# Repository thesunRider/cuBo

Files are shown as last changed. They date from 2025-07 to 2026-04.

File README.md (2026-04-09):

# cuBo
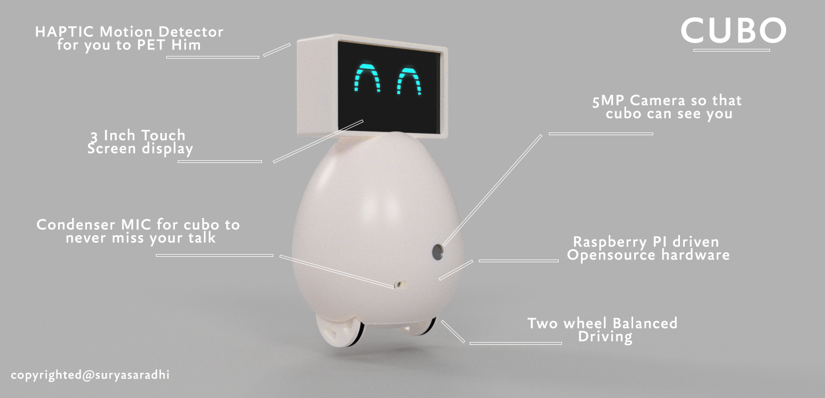
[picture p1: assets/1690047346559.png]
Description

### Autonomous Companion Robot for Modern Homes

**cuBo** is an open-source, interactive, autonomous companion robot designed for modern homes, running on a Raspberry Pi Zero 2 W with Raspberry Pi OS Bullseye Lite. Developed by **Leena Kashyap**,**Suryasaradhi Balarkan** and **Haris Mujeeb**.cuBo blends affordable hardware with AI-based software to deliver:

* Video streaming
* Expressive robotic eye animations
* Voice interaction
* Sensor-based gesture control
* Mobility

cuBo functions as a home automation hub, elderly care companion, educational assistant, and mobile surveillance system, requiring minimal user management. It reacts to touch and voice with emotional expressions, making it an engaging and relatable companion.

For setting up cubo : read implementations.md
---

## 🎯 Purpose

cuBo addresses key challenges in smart home robotics:

* **Emotional Interaction**: Unlike static assistants (e.g., Alexa, Google Home), cuBo offers physical movement and expressive animations.
* **Elderly Care**: Provides companionship, reminders, and emergency alerts for seniors.
* **Affordability**: Uses low-cost components to make personal robotics accessible.
* **Unified Automation**: Acts as a central hub for smart devices, schedules, and communication.

---

## 🚀 Features

* **Video Streaming:** 1080p30 video over UDP with `libcamera-vid` + `ffmpeg` for face/object tracking.
* **Display:** Robotic “RoboEyes” animations on a 3.5” SPI LCD (`/dev/fb0` framebuffer).
* **Audio:** Speech recognition (VOSK/Whisper) and audio playback via I2S.
* **Mobility:** 28BYJ-48 stepper motors for movement (head/wheel), controlled via Arduino Micro.
* **Sensors:** Compass (QMC5883P), TOF sensor (VL53L3CX), touch sensors for gesture input.
* **Automation:** Flask server for smart device control, scheduling, and remote access.

---

## Demo Video 
The below is Unfinished first cuBo prototype

https://github.com/user-attachments/assets/90a2a3a3-cf43-4fe5-9dd7-d7a50253ca3a

## 🧰 Hardware Components

| Component | Function |
| --- | --- |
| Raspberry Pi Zero 2 W | Main processor (AI, video, audio, control) |
| Arduino Micro | Motor and sensor control |
| OV5640 Camera | Video streaming & object detection |
| INMP411 Microphone | Voice input |
| 3.5" SPI LCD | Display animations/UI |
| MAX98357A Speaker | Audio output |
| Touch Sensor | Gesture/touch detection |
| 28BYJ-48 Stepper Motors | Movement (head/wheels) |
| ULN2003 Driver Board | Stepper motor driver |
| VL53L3CX TOF Sensor | Distance measurement (obstacle detection)  |
| QMC5883P Compass | Orientation detection |
| 3.7V Li-ion Battery | Power source |
| TP4056 Module | Battery charging & protection |
| 5V Boost Converter | 5V regulated power |
| Flask Server (via WiFi) | Remote control and streaming backend |

---

## 💾 Software Stack

### Raspberry Pi

* **OS:** Raspberry Pi OS Bullseye Lite
* **Languages:** Python, C++
* **Frameworks:**

  * ROS (sensor & navigation control)
  * Flask (web interface & automation)
  * ORB-SLAM (planned for future navigation)
* **AI:**

  * VOSK/Whisper for speech recognition
  * Ollama (planned for advanced AI chat)
* **Libraries:** `numpy`, `pyserial`, `picamera`, `libcamera-apps`, `ffmpeg`, `U8glib`, `PIGPIO`
* **Networking:** WiFi (video streaming, remote server)

### Arduino

* **Libraries:** `TinyStepper_28BYJ_48`, `ezButton`, `Wire`
* **Functions:** Motor & sensor control, UART bridge for Pi communication

### Design Tools

* **Fusion 360:** CAD modeling
* **KiCad:** PCB design
* **Flutter:** Mobile App (optional)

---

## ⚙️ Setup Instructions

### 1. Raspberry Pi Configuration

* Install Raspberry Pi OS Bullseye Lite
* Network Setup:

  ```bash
  nmap -p 22 --open -sV <subnet>.0/24  # Scan
  ping <ip>                            # Test
  ```
* Enable mDNS:

  ```bash
  sudo apt update
  sudo apt install avahi-daemon
  sudo systemctl enable avahi-daemon
  sudo systemctl start avahi-daemon
  sudo raspi-config  # Set hostname
  ping <hostname>.local
  ```

### 2. Camera & Streaming

* Enable camera (`raspi-config` + `/boot/config.txt`)
* Install tools:

  ```bash
  sudo apt install ffmpeg libcamera-apps tio
  ```
* Stream Video:

  ```bash
  libcamera-vid -t 0 -g 10 --bitrate 4500000 --inline --width 1920 --height 1080 --framerate 30 --rotation 180 --codec libav --libav-format h264 --av-sync 200000 -n -o udp://<receiver-ip>:1234
  ```
* View Stream:

  ```bash
  ffplay -fflags nobuffer -flags low_delay -framedrop udp://<receiver-ip>:1234
  ```

### 3. Audio Setup

* Enable I2S in `/boot/config.txt`:

  ```bash
  dtparam=i2s=on
  dtoverlay=googlevoicehat-soundcard
  ```
* Test Audio:

  ```bash
  aplay -l
  speaker-test
  arecord -d 5 test.wav
  aplay test.wav
  ```

### 4. Display Setup

* Connect 3.5" SPI LCD (via guide)
* Framebuffer Test:

  ```python
  import numpy as np
  fb = np.memmap('/dev/fb0', dtype='uint8', mode='w+', shape=(1024, 1280, 4))
  fb[:] = [255, 0, 0, 255]  # Blue screen
  ```

### 5. Sensor & Motor Control

* Upload Arduino code for stepper motors, buttons, compass, UART.
* Serial communication via `/dev/ttyS0` or `/dev/ttyUSB0`.
* Command Format:

  * `sm` (motor control), `swa` (button input), `cmps` (compass data).

### 6. RoboEyes Animation

* Expressive eye animations at 7 FPS:

  ```python
  robo = RoboEyes(lcd, 480, 320, frame_rate=7, on_show=robo_show)
  robo.set_auto_blinker(True, 4, 2)
  robo.set_idle_mode(True, 5, 2)
  robo.mood = DEFAULT
  robo.curious = True
  ```

---

## 🛠️ Implementation

* **Design:** Modeled in Fusion 360 with multiple design iterations.
* **Hardware:** Integrated stepper motors, sensors, audio, display.
* **Software:**

  * Python: AI, video, audio, LCD, server
  * Arduino: Motor & sensor control
  * Flask: Web interface & remote control
* **Testing:** Verified video streaming, sensor inputs, and animations.

---

## 🏠 Use Cases

* **Home Automation:** Control smart devices and routines.
* **Elderly Care:** Provide companionship, reminders, and emergency alerts.
* **Education:** Engage children with learning tools.
* **Surveillance:** Mobile camera for security monitoring.
* **Ambient:** Display info, play music, and show notifications.

---

## 🔮 Future Plans

* Integrate ORB-SLAM for autonomous navigation.
* Develop IoT backend for device integrations.
* Enhance AI with Whisper or ChatGPT.
* Integrate popular apps (Skype, WhatsApp).
* Connect to Google IoT for alarms and calendars.
* Add native language speech support.
* Design compact PCB for space optimization.
* Upgrade mechanical design with faster motors.
* Improve gesture recognition accuracy.

## 📄 License

MIT License

---

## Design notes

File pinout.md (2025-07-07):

## Connections

### Arduino
4 - step 1
5 - step 1
6 - step 1
7 - step 1

8 - step 2
9 - step 2
10 - step 2
11 - step 2

2 - sda
3 - scl

->  Connected: TMF8801, QMC5883L , ULNBYJ-248 ,  Touch sensors 

### Rpi Zero

bcm21 - din
bcm20 - dout
bcm19 - lrclk
bcm18 - bclk
bcm4 - Arduino Reset
bcm14 - Uart RX
bcm15 - Uart TX

bcm17 - TP_IRQ
bcm24 - LCD_RS	
bcm10 - LCD_SI / TP_SI	
bcm9 - TP_SO	
bcm25 - RST	
bcm11 - LCD_SCK / TP_SCK	
bcm8 - LCD_CS	
bcm7 - TP_CS	

-> Connected: INMP441, MAX98357A , OV5640 , Display

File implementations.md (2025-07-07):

## Pi Zero 2 W Setup
Pi Zero 2 OS: Bullseye Lite

Scanning for the pi before mDns is enabled can be done using
```bash
ipconfig or ifconfig (Windows or linux)
nmap -p 22 --open -sV subnet.0/24
ping <Scanned ip>
```

1. Setup mDNS on Raspberry pi
On windows you can use: https://support.apple.com/kb/DL999 to install mDNS resolution

```bash
sudo apt update
sudo apt install avahi-daemon
sudo systemctl enable avahi-daemon
sudo systemctl start avahi-daemon
systemctl status avahi-daemon
sudo raspi-config #set Hostname here

ping yourhostname.local #should work now
```

2. Setting up Camera and Streaming
1. Enable camera autodetect in boot config
2. Enable Camera in raspi-config
3. Install tools
```bash
sudo apt install ffmpeg -y
sudo apt install libcamera-apps
sudo apt-get install tio
```

4. Stream accessed using ffmplay commandon network using:
```bash
libcamera-vid -t 0 -g 10 --bitrate 4500000 --inline --width 1920 --height 1080 --framerate 30 --rotation 180 --codec libav --libav-format h264  --av-sync 200000 -n -o  udp://(recievingcomputersip):1234
ffplay -fflags nobuffer -flags low_delay -framedrop udp://(recievingcomputersip):1234
```
5. For autostart follow: https://medium.com/@celecavac/building-your-own-wifi-camera-with-raspberry-pi-zero-w-6d59b494e0c9

3. Setting Up MIC and Speaker Simultaneously

PI Zero has only one I2S peripheral, we are sharing the right channel for ASpeaker output and the left channel for audio in, for this we are using the `dtoverlay=rpigooglevoicehat-ssoundcard`
Enable overlays;
```bash
#This is /boot/config.txt
dtparam=i2s=on
dtoverlay=googlevoicehat-soundcard
```

##  USeful tools

Tools used in setting up pi zero 2 w streaming section
```bash
1. aplay -l
2. speaker-test
3. arecord -l
4. arecord -d 5 test.wav
5. aplay test.wav
6. v4l2-ctl --list-devices #list cameras
7. libcamera-hello
8. arecord --dump-hw-params -D hw:<card_id>,<device_id>
9. ls -l /dev/serial*
10. ls -l /dev/
11. fbset -fb /dev/fb0 
12. tvservice -d edid # Retrieve EDID settings from monitor and write into a file called "edid"
13. edidparser edid # Parse the file we just created to see what the attached monitor is capable of
```

4. Setup Display
Check display Connections
Follow: https://techeonics.com/setting-up-lcd-display-with-raspberry-pi/

No need for any window manager, we can directly write to the fb as follows
```python
import numpy as np

# Map the screen as Numpy array
# N.B. Numpy stores in format HEIGHT then WIDTH, not WIDTH then HEIGHT!
# c is the number of channels, 4 because BGRA
h, w, c = 1024, 1280, 4
fb = np.memmap('/dev/fb0', dtype='uint8',mode='w+', shape=(h,w,c)) 

# Fill entire screen with blue - takes 29 ms on Raspi 4
fb[:] = [255,0,0,255]

# Fill top half with red - takes 15 ms on Raspi 4
fb[:h//2] = [0,0,255,255]

# Fill bottom right quarter with green - takes 7 ms on Raspi 4
fb[h//2:, w//2:] = [0,255,0,255] 
```

Rewriting robot eyes to fit framebuffer

Need to implement swipe gestures and distance detection in sensor

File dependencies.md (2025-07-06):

Arduino dependencies:
	TinyStepper_28BYJ_48.h

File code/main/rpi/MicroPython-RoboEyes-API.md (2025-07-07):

# Introduction

This document describe the __RoboEyes__ and __Sequences__ classes.

# RoboEyes class

The RoboEyes is the main class used to control the properties and animation of the Eyes.

Note that `self`  is part of the Python class definition.

## \_\_init\_\_() method

Class constructor.

```
def __init__(self, fb, width, height, frame_rate=20, on_show=None, bgcolor=BGCOLOR, fgcolor=FGCOLOR ):
```

* __fb__ : FrameBuffer into which the RoboEyes will be drawed the Eyes.
* __width__ : Width of the FrameBuffer in Pixels
* __height__ : Height of the FrameBuffer in Pixels
* __frame_rate__ : Max frame rate to refresh the screen. Higher is the autorized rate, and smoother the animation will be.
* __on_show__ : callback event executed by RoboEyes when framebuffer data should be sent to the display.
* __bgcolor__ : color used for the background. This value is sent immediately to the FrameBuffer drawing routines.
* __fgcolor__ : color used for the foreground drawing.

Minimal setup example:

``` python 
from machine import I2C, Pin
from roboeyes import *
import ssd1306
import time

i2c = I2C( 1, sda=Pin.board.GP6, scl=Pin.board.GP7 )
lcd = ssd1306.SSD1306_I2C( 128, 64, i2c, addr=0x3d )

# RoboEyes callback event
def robo_show( roboeyes ):
	global lcd
	lcd.show()

robo = RoboEyes( lcd, 128, 64, frame_rate=100, on_show = robo_show )

while True:
	robo.update() 
```

## update() method

The `update` method is responsible for drawing each iteration of RoboEyes animation. The call to `update` only perform drawing at the proper timing to respect the desired frame_rate. The `update` method is also responsible to trigger the `on_show` event.

When called to early the method will simply return execution to the callee. 

The `update` method is also responsible to schedule the steps of a started sequence (see later in this document)

Do not hesitate to call `update` as often as possible. 

## set_auto_blinker() method

Set automated eye blinking with minimal blink interval and blink interval variation range.

Note that set_auto_blinker() must be disabled when using the `close()` and `open()` methods.

``` python
def set_auto_blinker( self, active, interval=None, variation=None):
```

* __active__ : use the constant ON and OFF. When activating, the `interval` (default 1) and `variation` (default 4) should ne set.
* __interval__ : minimum interval between 2 consecutive blink (in seconds).
* __variation__ : maximum random time to add to `interval` for the next blink (in seconds).

Example: 

``` python 
robo.set_auto_blinker( ON, 3, 2)
```

## set_idle_mode() method

Set automated eye repositioning with minimal time interval and time interval variation range.

``` python
def set_idle_mode( self, active, interval=None, variation=None)
```

* __active__ : use the constant ON and OFF. When activating, the `interval` (default 1) and `variation` (default 4) should ne set.
* __interval__ : minimum interval between 2 consecutive repositionning (in seconds).
* __variation__ : maximum random time to add to `interval` for the next repositionning (in seconds).

Example: 

``` python 
robo.set_idle_mode( ON, 2, 2)
```
## EYE GEOMETRY

### eyes_width() method

Set the width of each eyes.  Default value is 45 pixels.

```
def eyes_width( self, leftEye, rightEye)
```

Here an example of distinct eye width and eye height.

Distinct height & width for each eye

### eyes_height() method

Set the height of each eye. The default value is 45 pixels.

```
def eyes_height( self, leftEye, rightEye )
```

### eyes_radius() method

Define the radius to apply on corners of each eye. The default value is 8 pixels.

Using a 0 pixel radius will show __SQUARE eye__. Having `Height = Width` and `radius = Height / 2` will show a __ROUND eye__.

```
def eyes_radius( self, leftEye, rightEye)
```

Here an example of disctinct radius value.

Distinct radius for each eye

### eyes_spacing() method

Set the space between the both eyes. The default value is 10 pixels.

Space can be lower and negative, giving a very special look to your eyes.

```
def eyes_spacing( self, space )
```

Example:

``` Python
from machine import I2C, Pin
from roboeyes import *
import ssd1306
import time

# Raspberry-Pi Pico - I2C(1)
i2c = I2C( 1, sda=Pin.board.GP6, scl=Pin.board.GP7 )
# Adafruit 938 : Monochrome 1.3" 128x64 OLED graphic display - SSD1306
# SSD1306_I2C is a descendant of FrameBuf 
lcd = ssd1306.SSD1306_I2C( 128, 64, i2c, addr=0x3d )

# RoboEyes callback event
def robo_show( roboeyes ):
	global lcd
	lcd.show()

robo = RoboEyes( lcd, 128, 64, frame_rate=100, on_show = robo_show )
# Define some automated eyes behaviour
robo.set_auto_blinker( ON, 3, 2) 
robo.set_idle_mode( ON, 2, 2) 
# Round Eye definition
robo.eyes_width(45, 45) 
robo.eyes_height(45, 45)
robo.eyes_radius(8, 8)
robo.eyes_radius(22, 22)
robo.eyes_spacing(-7)

while True:
	robo.update()  
```

Which produce the following eyes.

Round Eyes with negative spacing

### Sequences property

Give access to various sequence. See the definition of the `Sequences` class.

### cyclops property

Setting the `cyclops` boolean property will activate the Cyclop mode (show only one eyes).

```
@cyclops.setter
def cyclops( self, enabled ):
```

Notice: the `def set_cyclops( self, value )` can be used for creating lambda expression.

``` python
from machine import I2C, Pin
from roboeyes import *
import ssd1306
import time

# Raspberry-Pi Pico - I2C(1)
i2c = I2C( 1, sda=Pin.board.GP6, scl=Pin.board.GP7 )
# Adafruit 938 : Monochrome 1.3" 128x64 OLED graphic display - SSD1306
# SSD1306_I2C is a descendant of FrameBuf 
lcd = ssd1306.SSD1306_I2C( 128, 64, i2c, addr=0x3d )

# RoboEyes callback event
def robo_show( roboeyes ):
	global lcd
	lcd.show()

robo = RoboEyes( lcd, 128, 64, frame_rate=100, on_show = robo_show )
# Define some automated eyes behaviour
robo.set_auto_blinker( ON, 3, 2) 
robo.set_idle_mode( ON, 2, 2) 
# Cyclop Eye definition
robo.eyes_width(20, 20) 
robo.eyes_height(45, 45)
robo.eyes_radius(0, 0)
robo.cyclops = True

while True:
	robo.update()  
```

Which produce the following eye.

Cyclops Eye

## mood property

Setting the `mood` property will update the dynamic eyes behaviour.

The possible values are the following constants: __DEFAULT, TIRED, ANGRY, HAPPY, FROZEN, SCARY, CURIOUS__.

```
@mood.setter
def mood( self, mood )
```

Notice: the `def set_mood( self, mood )` can be used for creating lambda expression.

The __DEFAULT__ value is the default mode where eyes a usually open.

The __TIRED__ will partially close the eyelid on the eyes.

The __ANGRY__ will make the eyebrows pointing back between the eyes.

The __HAPPY__ will curves/bump up the eyes.

The __FROZEN__ will make eyes slightly shaking from left-to-right (like your head would do when you are frozen).

The __SCARY__ will partially close the eyes and made it slightly shaking from top-to-bottom (like your jaw would do if you are afraid).

The __CURIOUS__ will increase the size of the eye near of the left or right border (behind the scene, this activates the `curious` property).

Example:

``` python
robo.mood = HAPPY 
```

## position property

Move the eyes on a given border/corner of the screen accordingly to the value __N, NE, E, SE, S, SW, W, NW__. The value __DEFAULT__ can be used to horizontally and vertically centered the eye.

```
@position.setter
def position( self, direction )
```

Compatible with an active `set_idle_mode()`, eye will start moving again after the eyes had moved in the target position. 

Notice: the `def set_position( self, direction )` can be used for creating lambda expression.

Example:

``` python
robo.position = SW 
```

## curious property

Set curious mode as the `robo.mood=CURIOUS` would do with a True / False parameter.

The respectively outer eye gets larger when looking left or right.

``` python
curious.setter
def curious( self, enable )
```

Notice: the `def set_curious( self, enable )` can be used for creating lambda expression.

## confuse() method

Make the eyes flicker left-and-right in a rather large distance (20 pixels) like shaking the head. 

The animation duration is about 500 ms.

``` python
def confuse( self )
```

## laugh() method 

Make the eyes jumping up and down (like laughing out loud) for 500 ms. This short animation is played once.

Notice that setting the `mood` to __HAPPY__ would gives a great result.

``` python
def laugh( self )
```

## blink() method

Activate eye blink sequence. This call make sense only when autoblinker is disable.

``` python
def blink( self, left=None, right=None )
```

## wink() method
Make either a left, either a right eye wink.

This call __disable the autoblinker and idle mode__.

``` python
def wink( self, left=None, right=None )
```

Example:

``` python
robo.wink( right=True )
```

## open() & close() method

Open or close the eyes. When closed, the eyes are reduced to a single line.

__Idle mode must be disabled__ when using thoses methods. See the [test_anim_sequence.py](examples/test_anim_sequence.py) .

## horiz_flicker() method

horizontal Eyes shaking/flickering. This basic method is used for several effect (eg: FROZEN mood).

``` python
def horiz_flicker( self, enable, amplitude=None )
```
* __enable__ : True/False to activate/deactivate horizontal Eyes flickering.
* __amplitude__ : flickering amplitude in pixels.

## vert_flicker() method

Same as `horiz_flicker()` but for vertical movement.

# Sequences class

The Sequences class is a list containing `Sequence`. Each `Sequence` contains a list of __Step__ (formmally `StepData` class).

The `RoboEyes.sequences` is used to define several `Sequence` (a `Sequence` is like one animation). 

Each `Sequence` can be started at any time by calling its `start()` method. When started, the `sequence` executes its various steps it contains, execution made at the right timing. 

Example:

The following code defines the `Sequence` named "demo" and the various steps it contains.

``` python
robo = RoboEyes( lcd, 128, 64, frame_rate=100, on_show = robo_show )

# RoboEyes can store several animation sequences 
#   Lets create the sequence ZERO
seq = robo.sequences.add( "demo" )
seq.step( 2000, lambda robo : robo.open() ) # at 2000 ms from start --> open eyes.
seq.step( 4000, lambda robo : robo.set_mood(HAPPY) ) # Lamba must call function! Cannot assign property! 
seq.step( 4010, lambda robo : robo.laugh() )
seq.step( 6000, lambda robo : robo.set_mood(TIRED) )
seq.step( 8000, lambda robo : robo.set_mood(DEFAULT) )
seq.step( 9000, lambda robo : robo.close() )
seq.step( 10000, lambda robo : print(seq.name,"done !") )  # Also signal the end of sequence at 10 sec
```

## add() method 

This method is called prior to define a new sequence of step (say: to define a new "animation").

Create a `Sequence` object, give it a name and register it into the `Sequences` list. 

The method returns a reference to the created `Sequence` objet. 

``` python 
def add( self, name  )
```

## done property

Check if all defined `Sequence` are done. The property is True when all started `Sequence` are done! (Note: a not started `Sequence` is always done).

``` python
@property
def done( self )
```

## update() method

That method check if any started `Sequence` it contains have a pending __Step__ to execute. If such then the pending __Step__ are executed.

``` python
def update( self )
```

# Sequence class

The `Sequence` class is container of __Step__ s (`StepData`). Each __Step__ defines a task to perform at a given time (after Sequence is started).

## step() method 

This method is used to add the definition of new __Step__ into the sequence.

``` python
def step( self, ms_timing, _lambda )
```
	
* __ms_timing__ : time in milliseconds after the Sequence start. Time when the __Step__ must be executed.
* __\_lambda__ : the function to execute. Must be a function or lambda expression receiving a RoboEyes instance as parameter.

As the \_lambda receives the robo (RoboEyes instance), the step can run action (method call) to change the Eyes behavior, mood, animation, etc.

Due to the limitation of the MicroPython parser, the lambda expression cannot make property assignation. This is the raison why the RoboEyes properties hase their equivalent `set_xxx()` method.

In the following lines:

``` python
seq.step( 6000, lambda robo : robo.set_mood(TIRED) )
seq.step( 8000, lambda robo : robo.set_mood(DEFAULT) )
```

The mood of the RoboEyes will be set to TIRED 6 seconds after the start of the sequence. The mood will be changed again to DEFAULT 8 seconds after the sequence start.

The `Sequence` will be set to "done" immediately after execution of the last __Step__. 

IF the `Sequence` must last longer than last step execution THEN just add a final step with a `print()` statement. That will delay the end of sequence execution until the `print()` is executed.

## start() method

Start the execution of the `Sequence`... meaning the execution of the __Step__ contained into the `Sequence`.

This method also set the _start_ flag and keeps track of the starting time (required to executes the __Step__ at the right time).

## reset() method

Reset the _start_ flag of the sequence as well as the `done` flag of all the __Step__ .

``` python
def reset( self )
```

## done property

Return `True` when all the steps of a started sequence are executed (are `done`).

A not started `Sequence` is always `done`! So the property return False only when one or more steps to be executed.

``` python
@property
def done( self )
```

## Update() method

Check if one of the defined __Step__s have to be executed. If so, it does it by calling the step.update().

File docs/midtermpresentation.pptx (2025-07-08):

## CUBO – Implementation Updates

Ubiquitous Lab Systems – MID TERM PRESENTATION

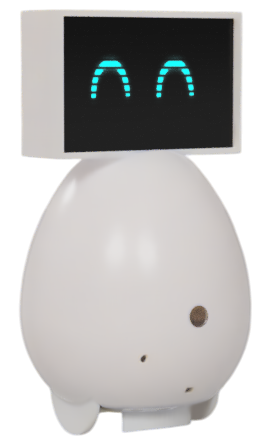
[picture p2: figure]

## Implementation Overview

1. Implemented the CAD model
2. Code testing
3. Connection Modelling
4. Simulation

## Hardware Procurement

Hardware Used:

1. Raspberry Pi Zero W - 1x
2. ULN8BYJ - Stepper motor - 2x
3. 5MP Camera Module for Raspberry Pi Zero
4. TOF Sensor (VL53L0x) - 1x or equivalent
5. 4inch LCD Module with touch screen SPI preferred - 1x
6. Capacitive touch sensor - 2x
7. Electret Mic module - 2x
8. Battery Overvoltage Protector - 1x
9. Battery Charger Module - 1x
10. Stepper Driver for ULN8BYJ - 1x
11. Wireless charging module - 1x
12. GPS module - 1x
13. IMU Module - 1x
14. IR obstacle sensor - 2x

## Implemented Code

Implemented Test code in python for :
1. Stepper movement with encoding
2. Camera realtime streaming
3. LCD Display with robotic eyes
4. Capacitive touch sensor
5. Sound Recording and Streaming
6. Ollama based model for AI end
7. Whisper AI backend for speech recognition

## Setbacks

1. No components available
2. Deadlines shifted
3. Code compilation time > 1 minute

## Expected Outcome

1. AI integrated bot
2. Speech recognition
3. Movement control by AI
4. Basic App Integration

## THANK YOU

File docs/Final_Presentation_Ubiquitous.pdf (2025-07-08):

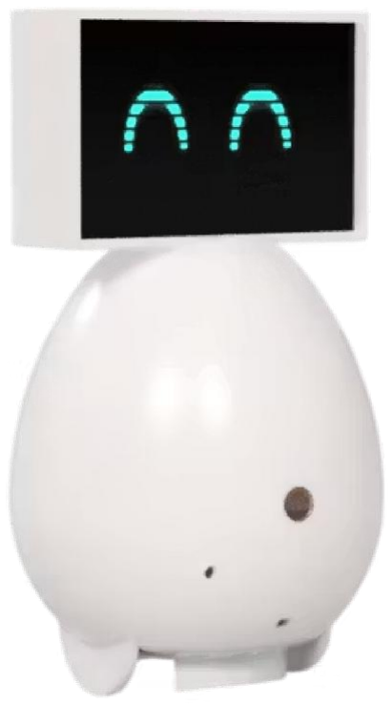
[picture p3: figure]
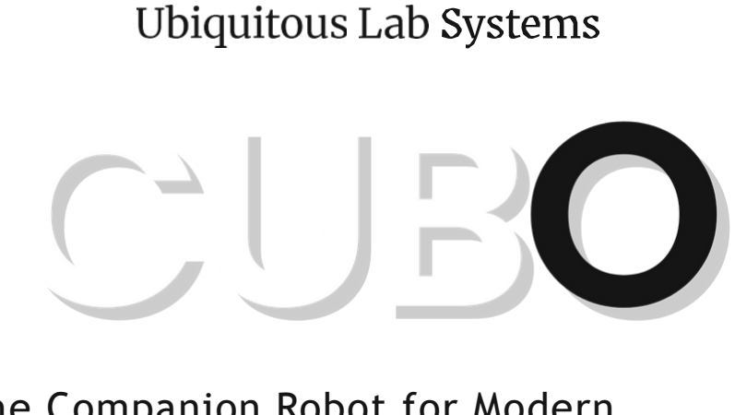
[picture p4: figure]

Team :
Leena Kashyap – 1786572
Suryasaradhi Balarkan - 1840580

The Companion Robot for Modern Homes

# Final Presentation

## The Problem

•

•

•

•

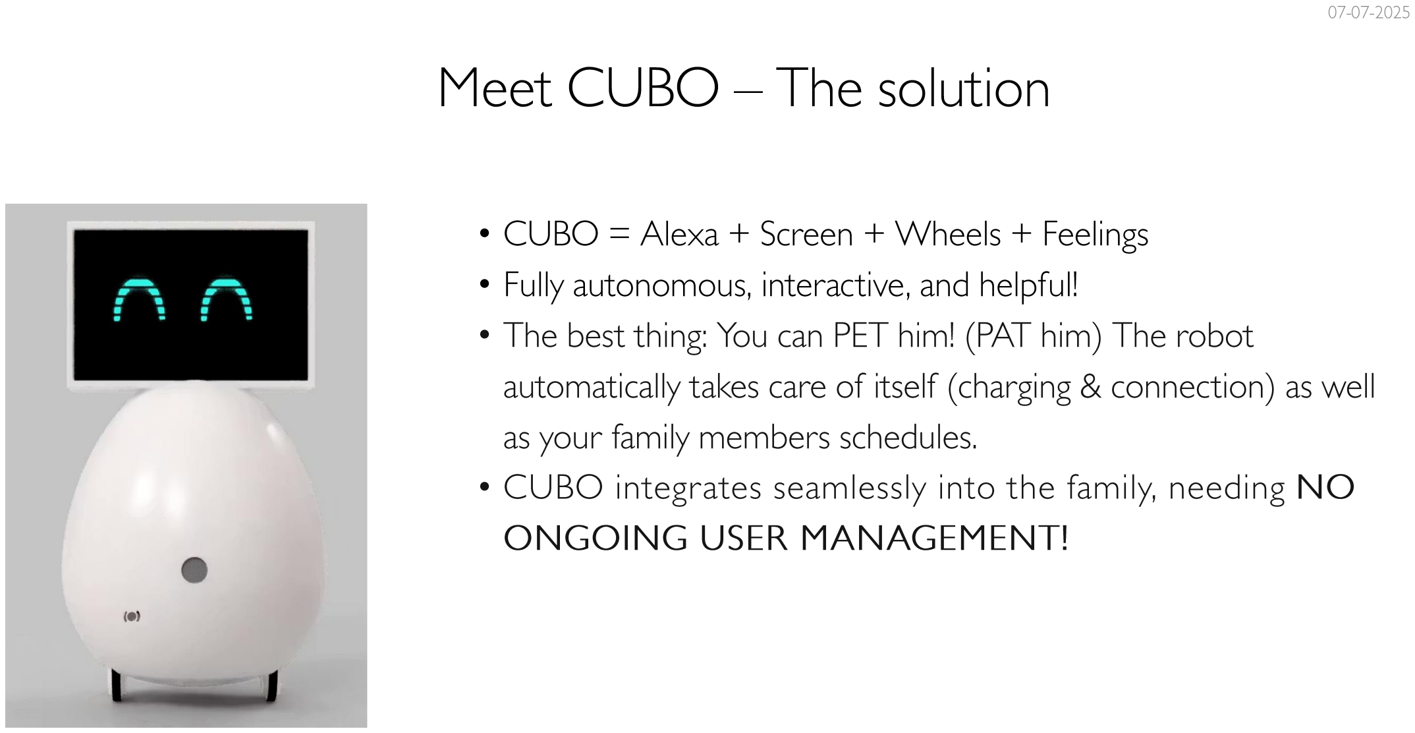
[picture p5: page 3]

••••

••••

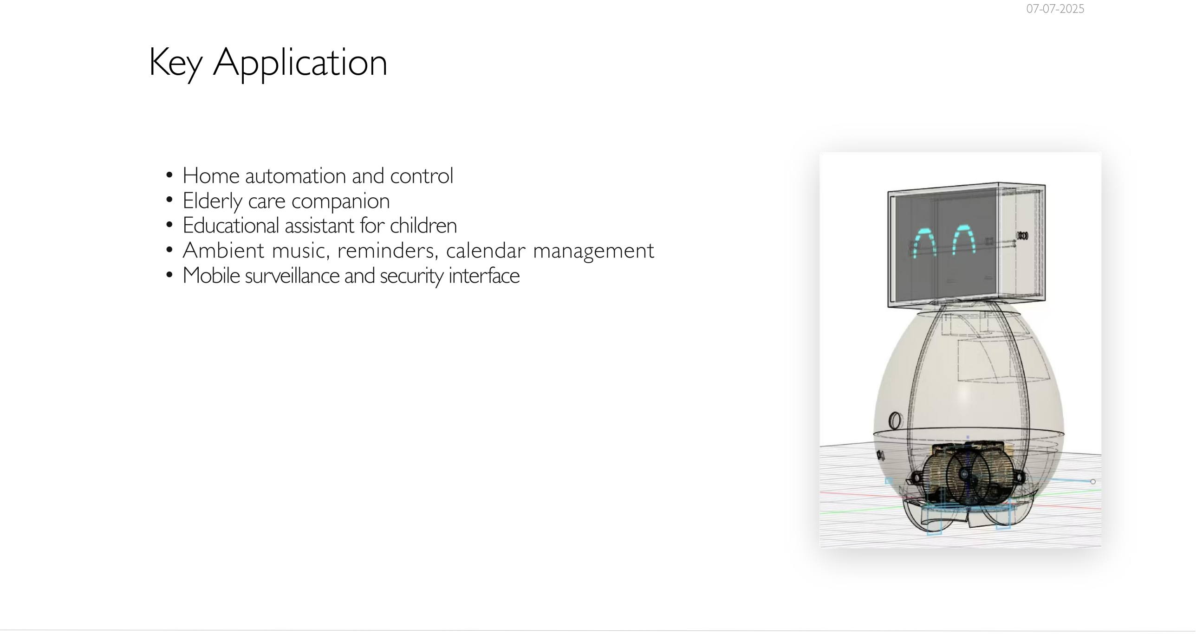
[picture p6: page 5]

•••••

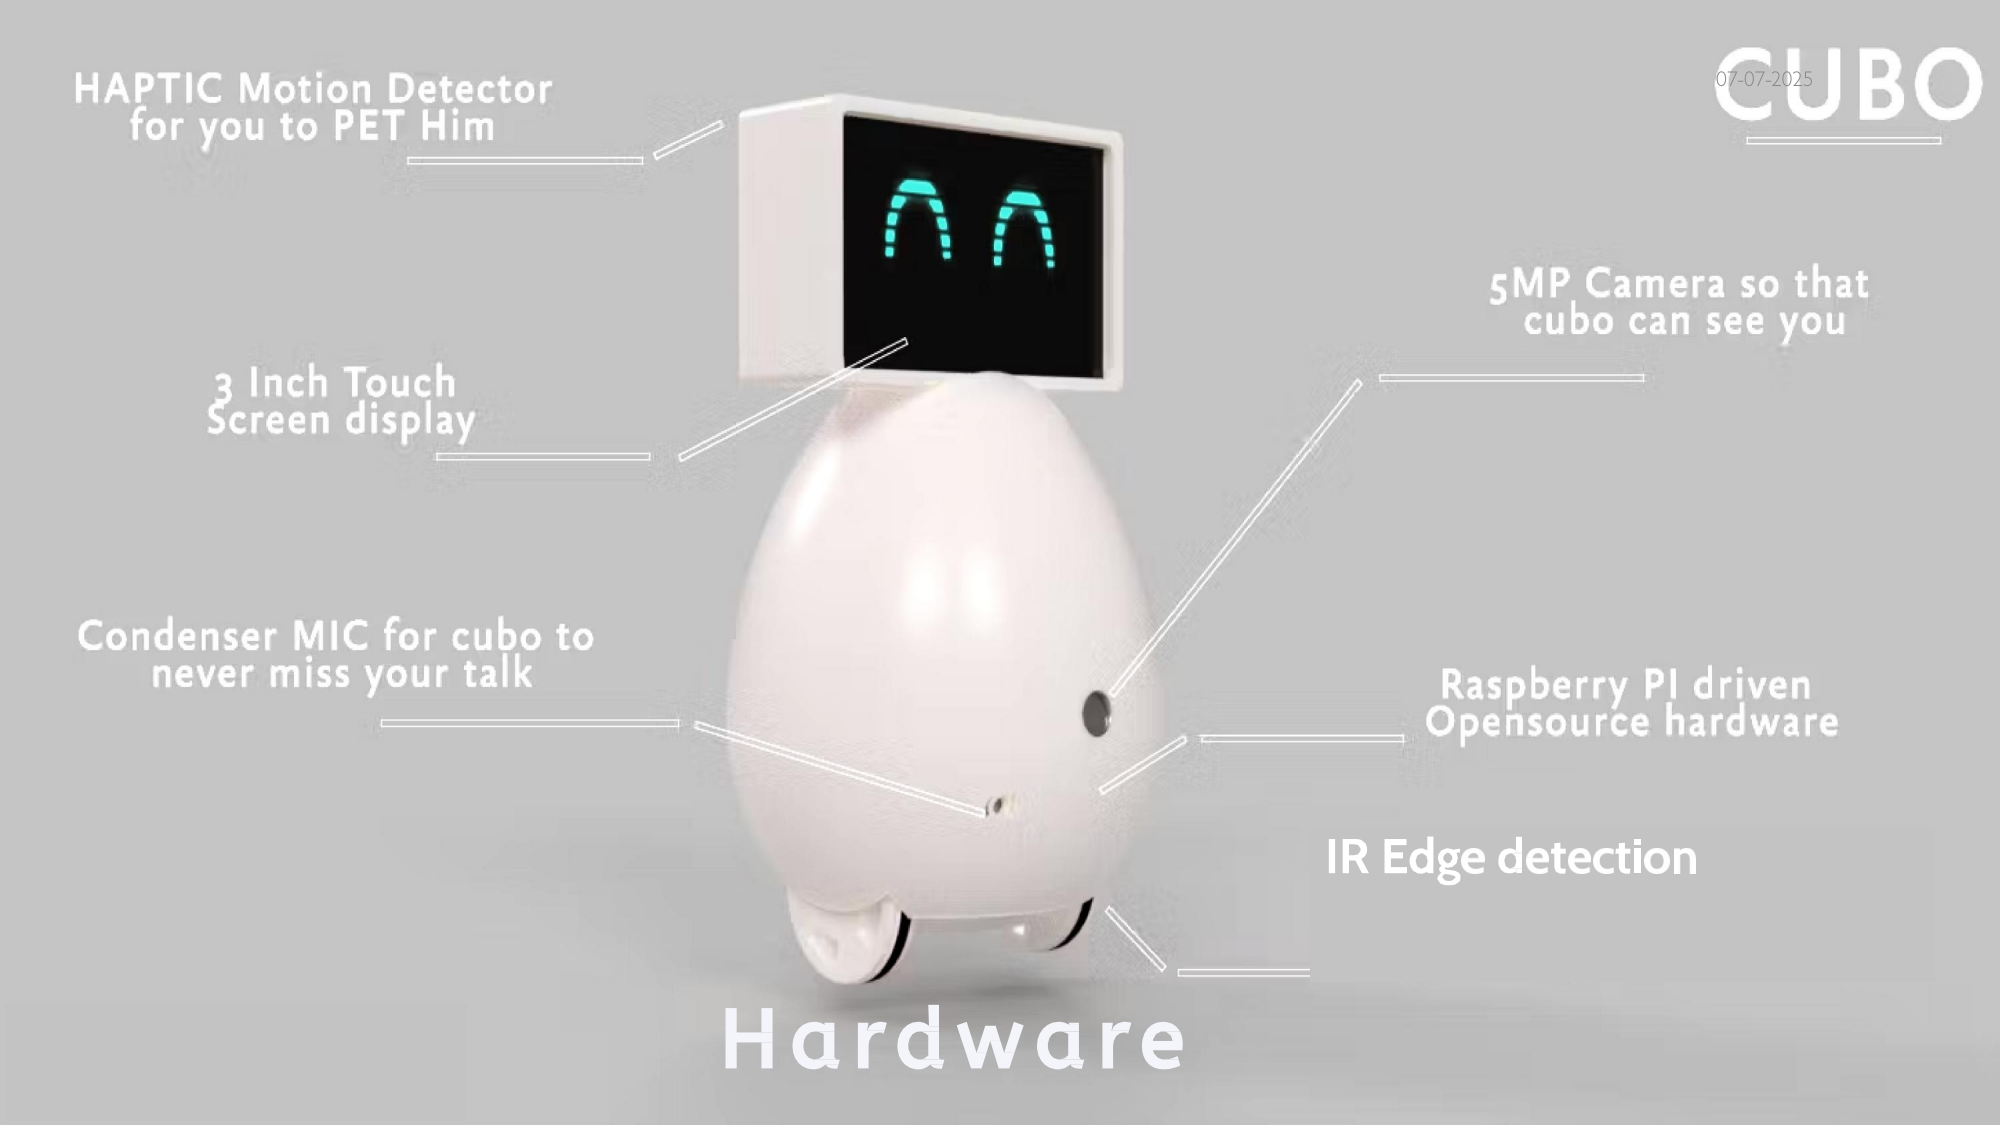
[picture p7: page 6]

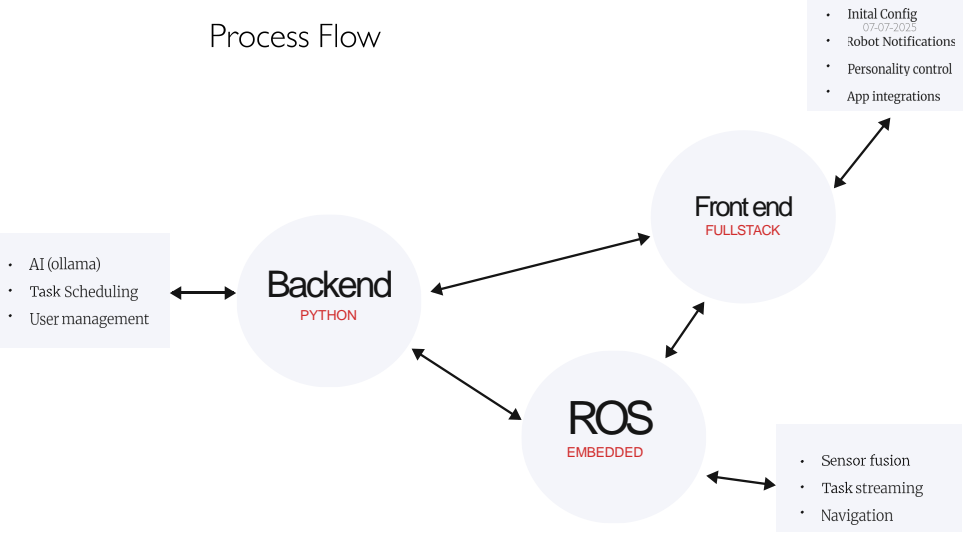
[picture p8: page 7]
Front end; FULLSTACK; Backend; PYTHON; ROS; EMBEDDED

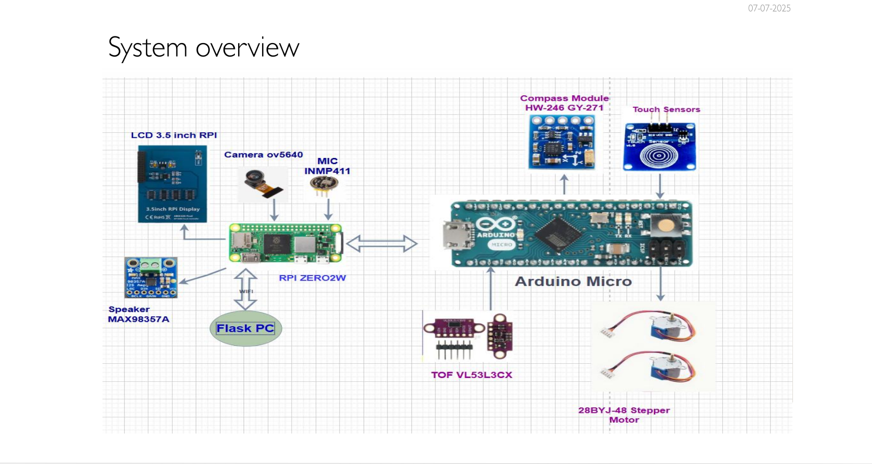
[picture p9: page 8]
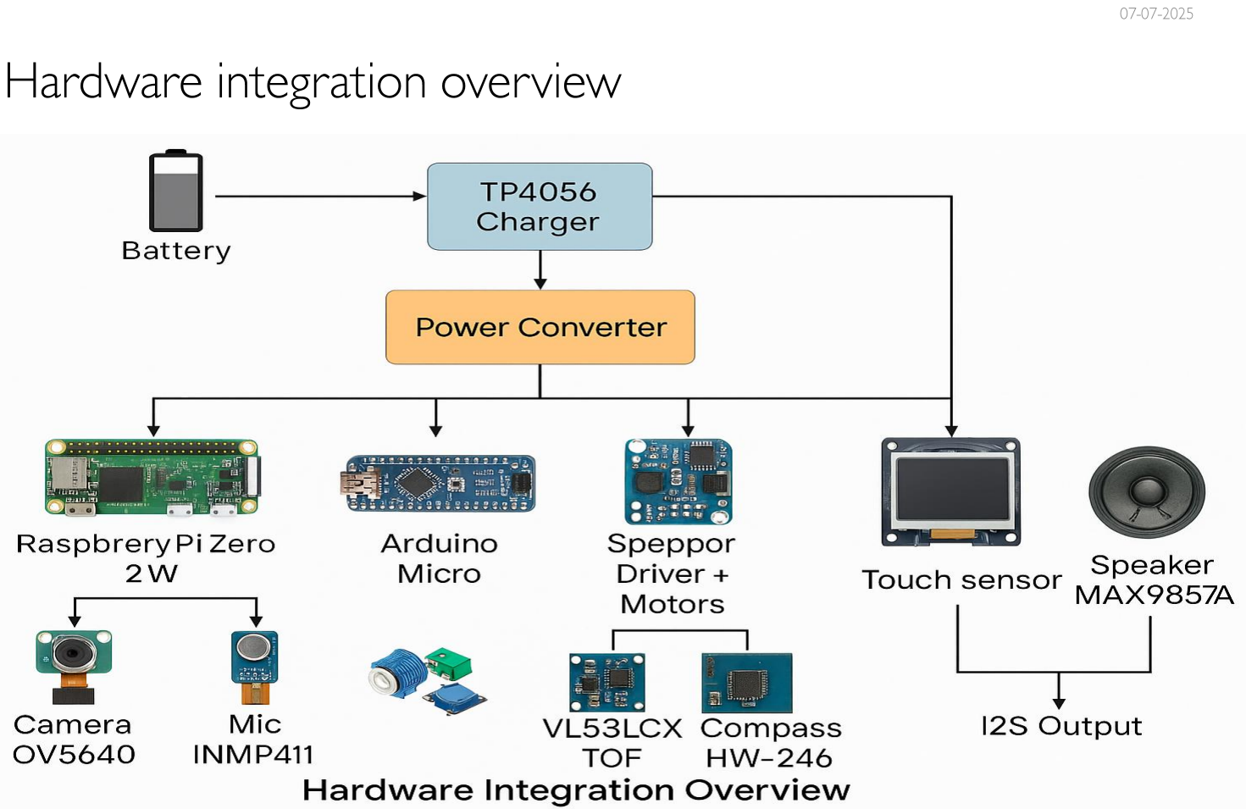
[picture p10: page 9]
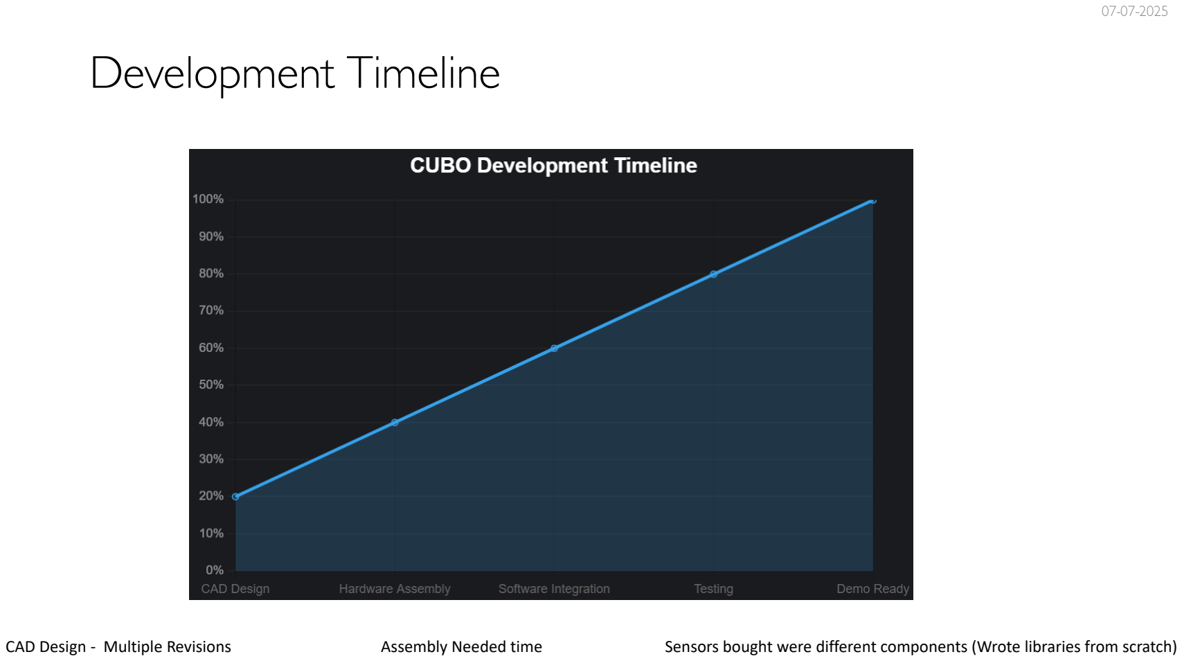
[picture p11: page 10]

CAD Design - Multiple Revisions | Assembly Needed time | Sensors bought were different components (Wrote libraries from scratch)

•••••••

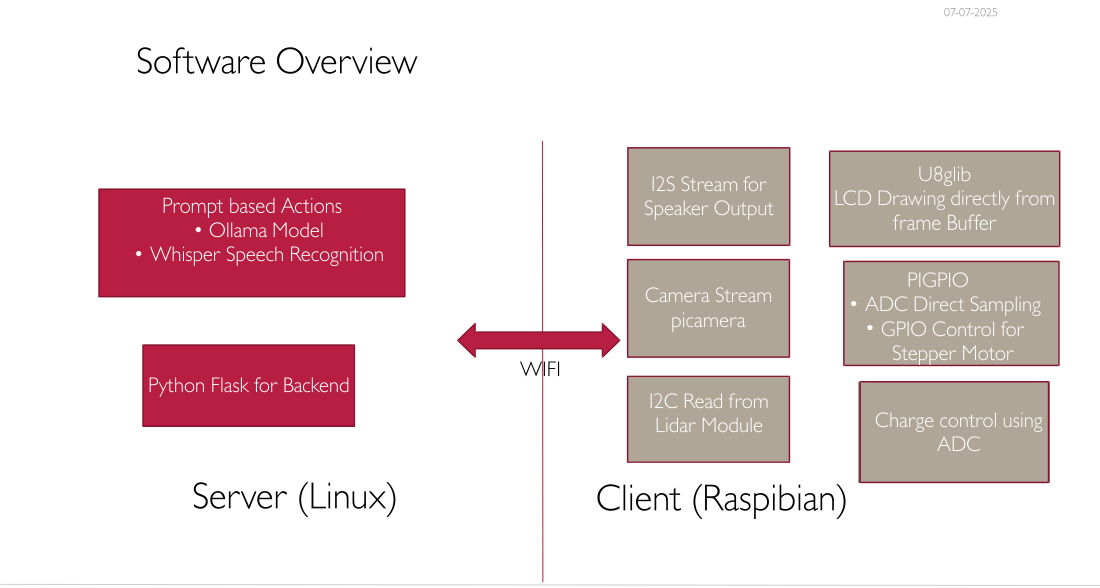
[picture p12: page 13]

## Code Snippet : Compass Module

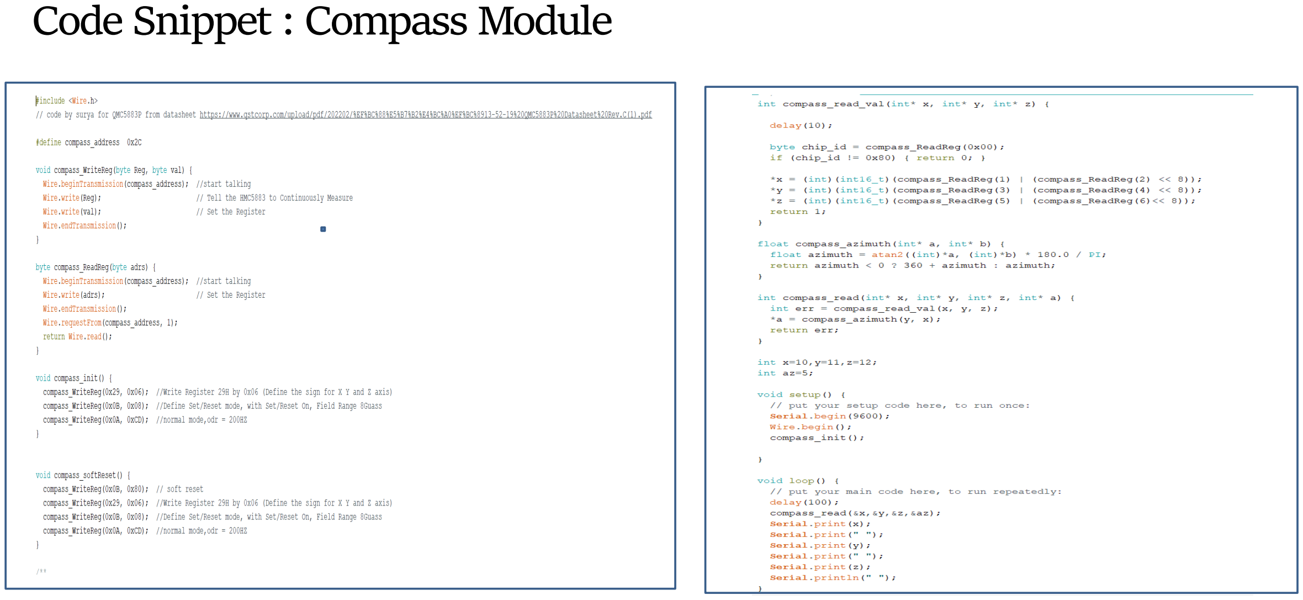
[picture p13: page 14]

## Code Snippet : Stepper

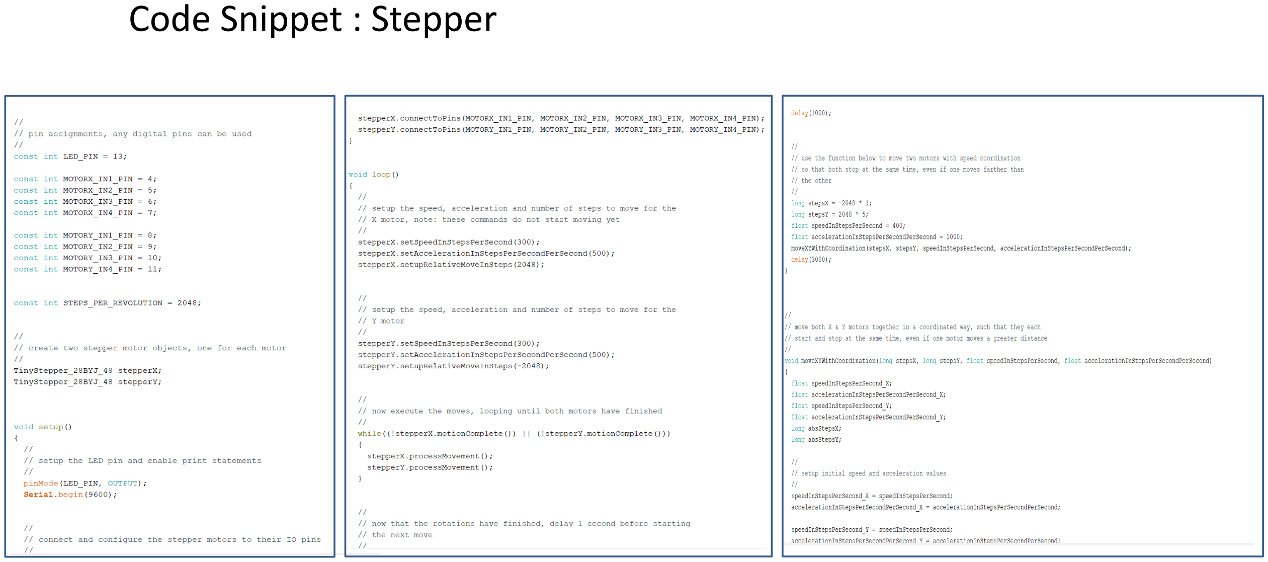
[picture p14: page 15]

## Code Snippet : TOF

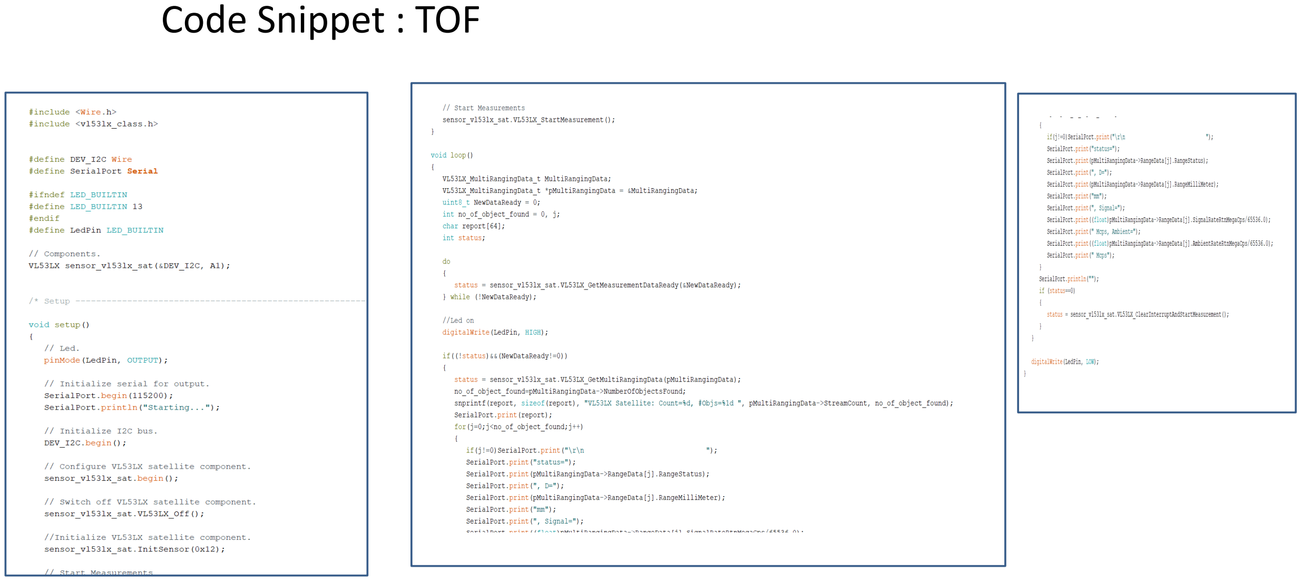
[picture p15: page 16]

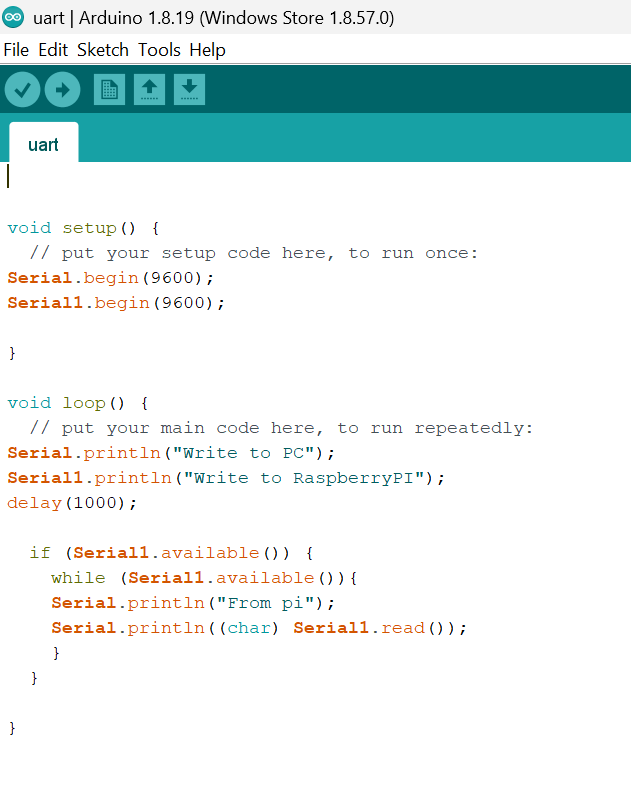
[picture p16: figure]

### Code Snippet : UART bridge for Micro to Raspberry Communication

## Code Snippet : Main code on Raspberry

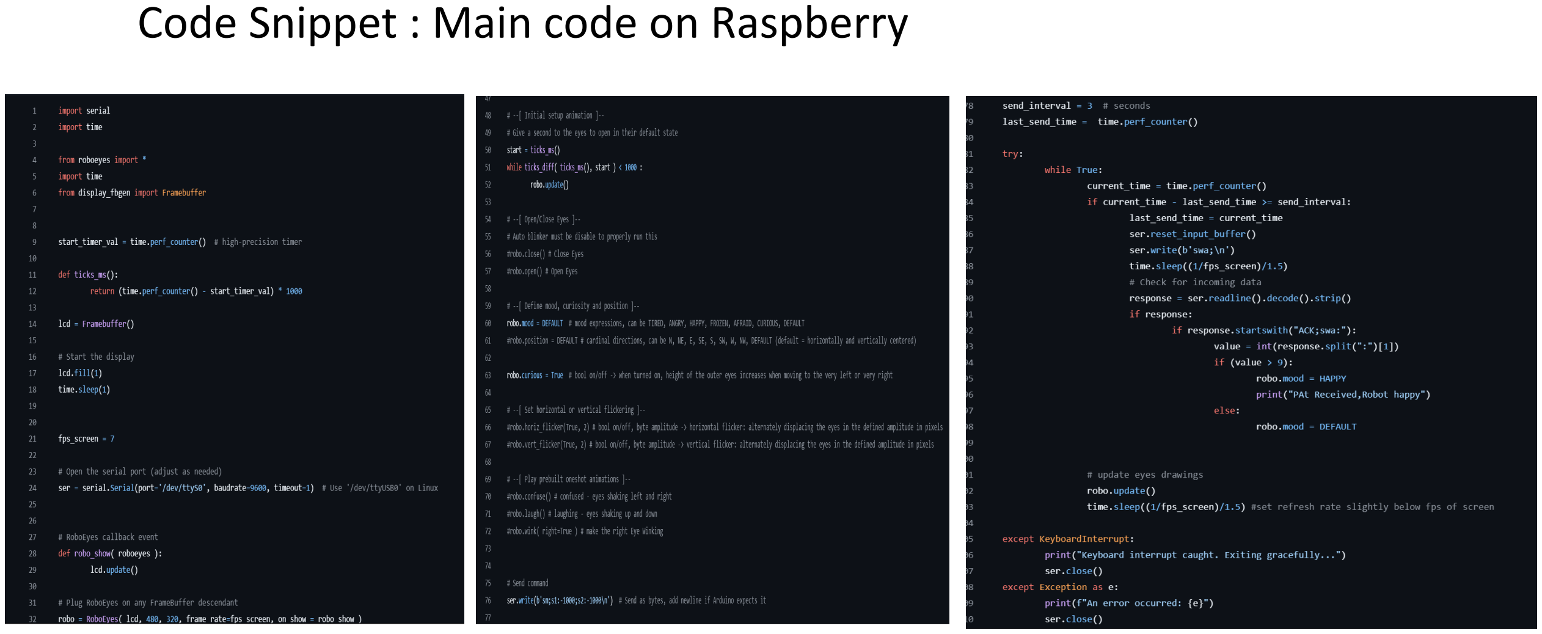
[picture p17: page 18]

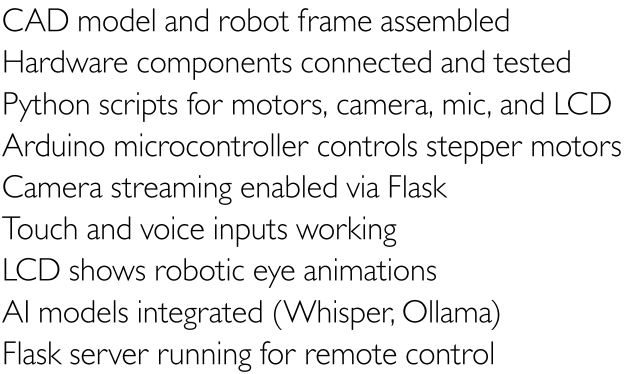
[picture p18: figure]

•••••••••

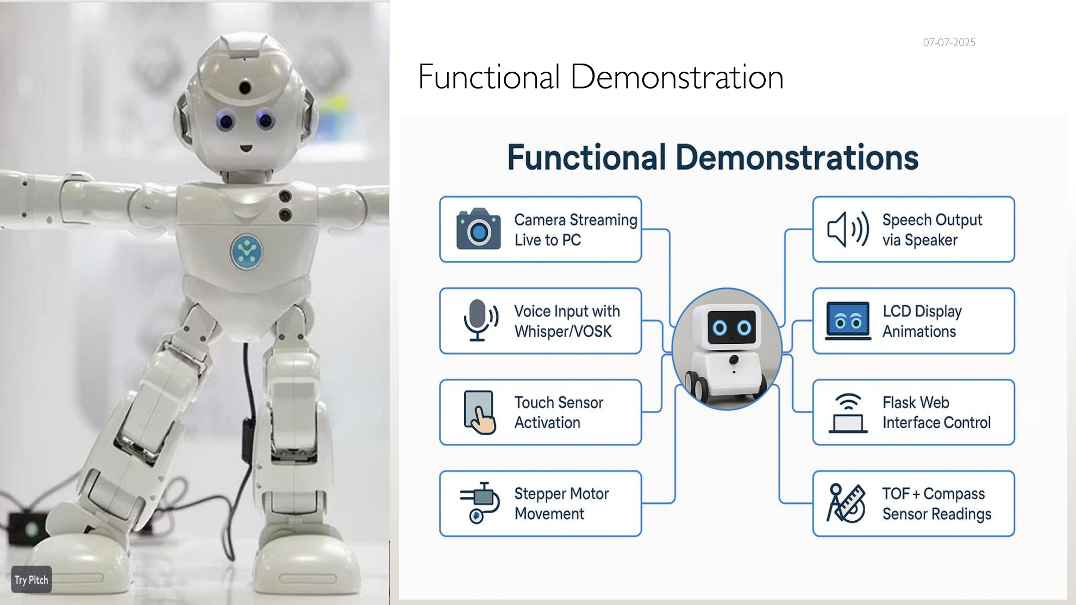
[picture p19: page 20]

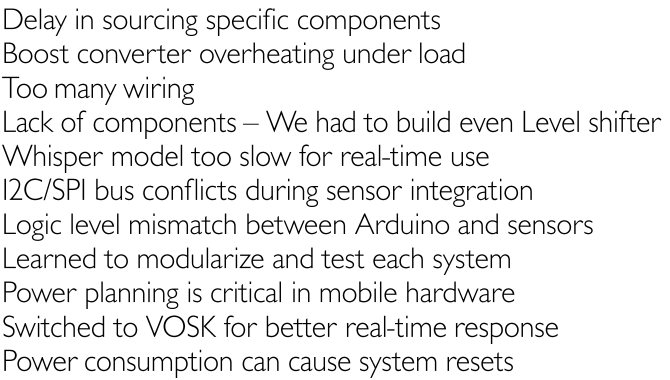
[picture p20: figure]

•••••••••••

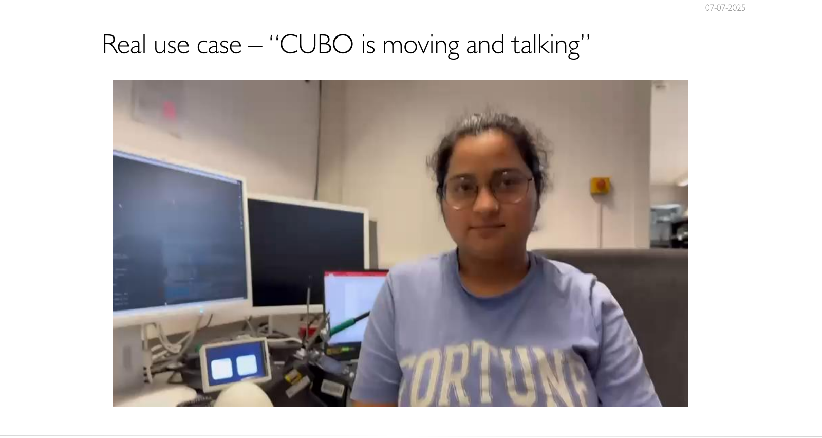
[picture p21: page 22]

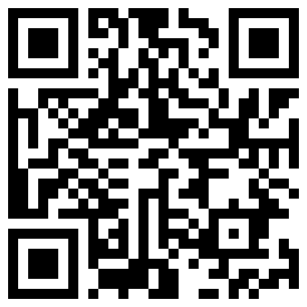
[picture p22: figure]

- (https://github.com/thesunRider/cuBo)
- Implement ORBSLAM • Implement IOT backend • Implement Whisper Model (switch from Vosk

)
- ChatGPT Integration (Switch from Ollama

)
- Add third party app integration

(Skype,Whatsap

)
- Connect to google IOT devices (Schedule alarms, Access calendars ..)
- Native language Speech Recognition • PCB design and implementation • Polishing Mechanical Design • Faster Stepper motors • Implement Gesture detection for user control

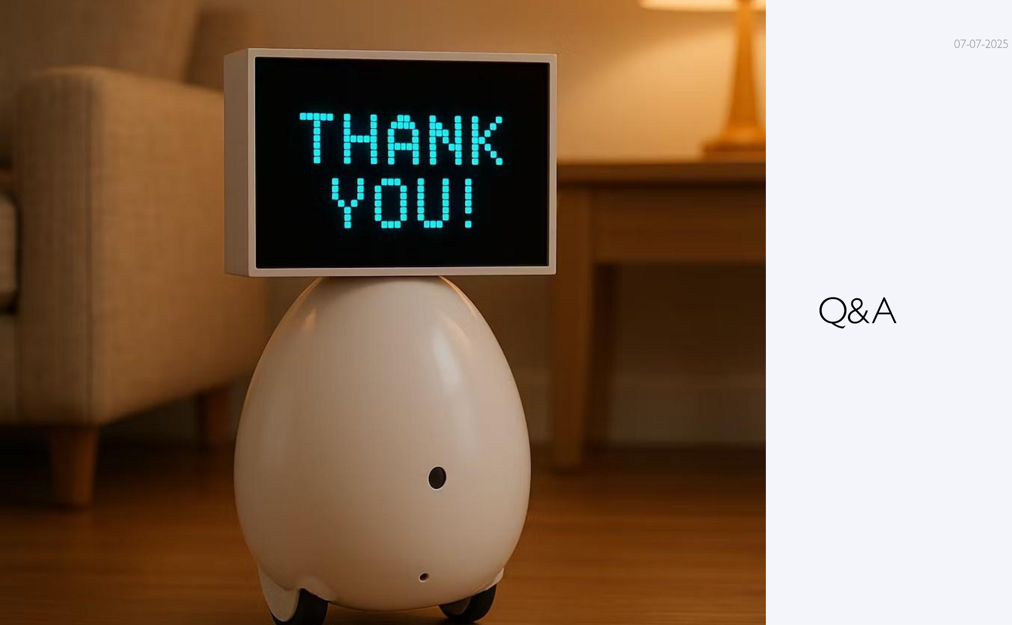
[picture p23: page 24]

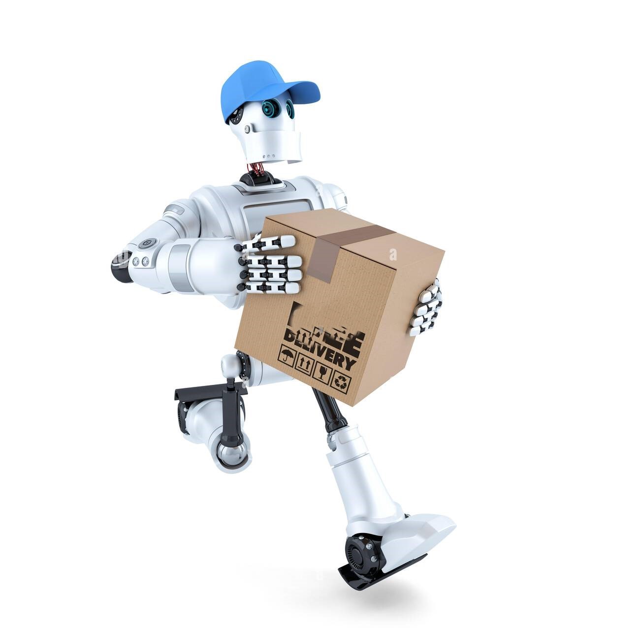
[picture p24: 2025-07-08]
assets/3d-courier-robot-with-package-free-delivery-concept-isolated-contains-clipping-path-2K2K5DE.jpg

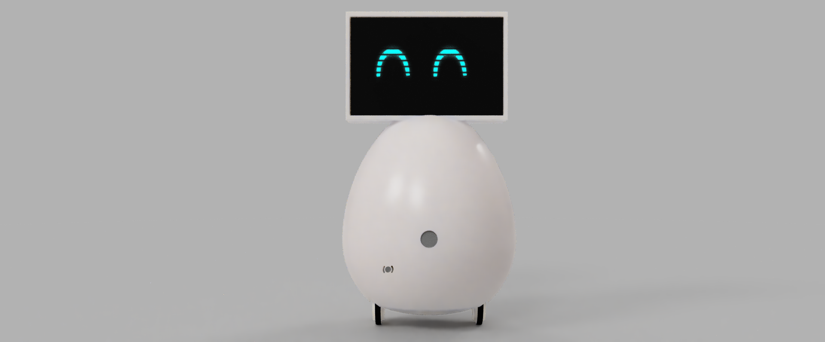
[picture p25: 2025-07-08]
assets/rnd2.png

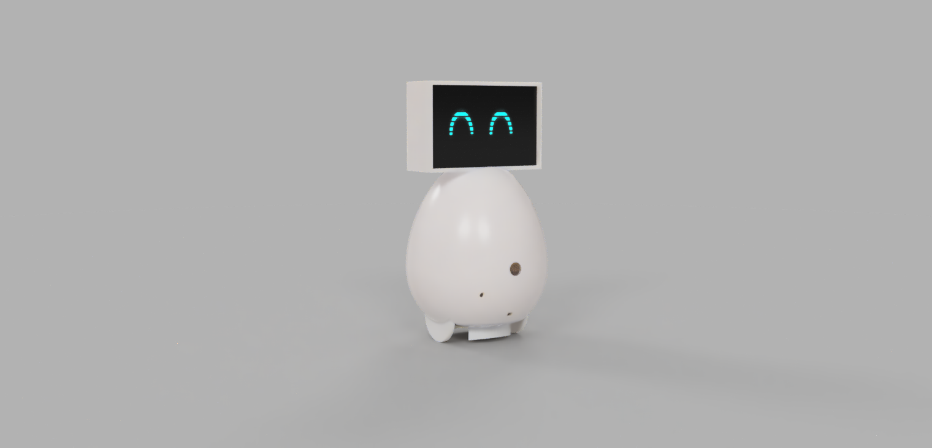
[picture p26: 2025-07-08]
assets/rnd1.png

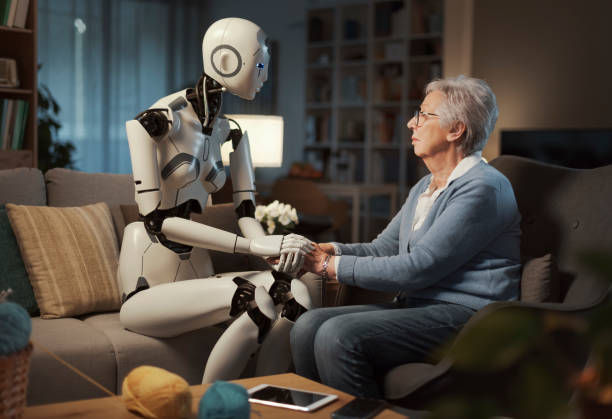
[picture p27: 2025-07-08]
docs/istockphoto-1472259484-612x612-1.jpg

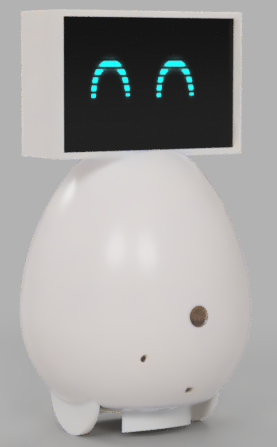
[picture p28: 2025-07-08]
assets/rnd1_crop.png

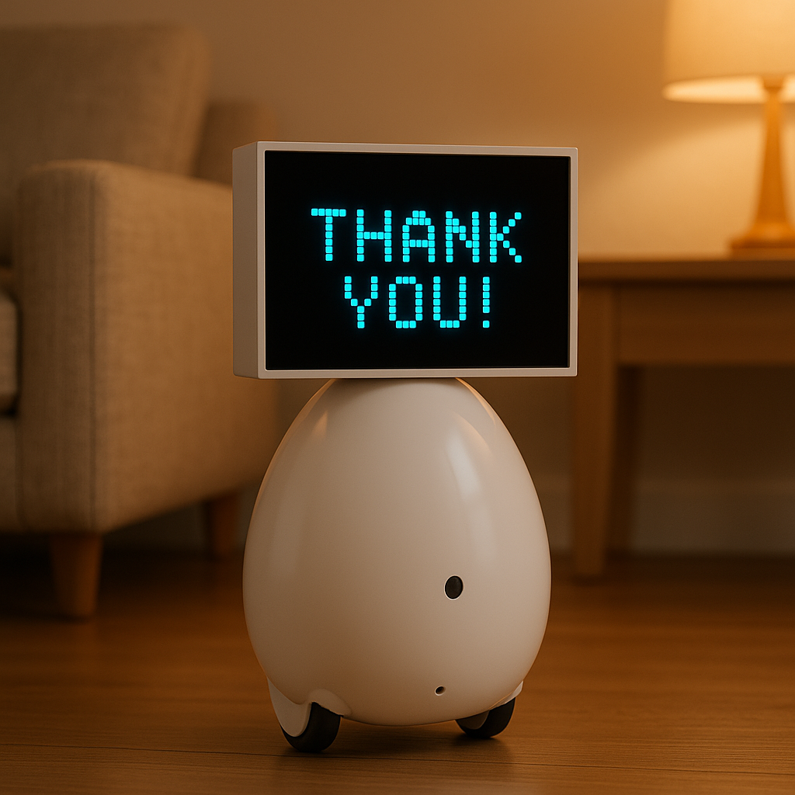
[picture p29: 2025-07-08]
assets/rnderthank.png

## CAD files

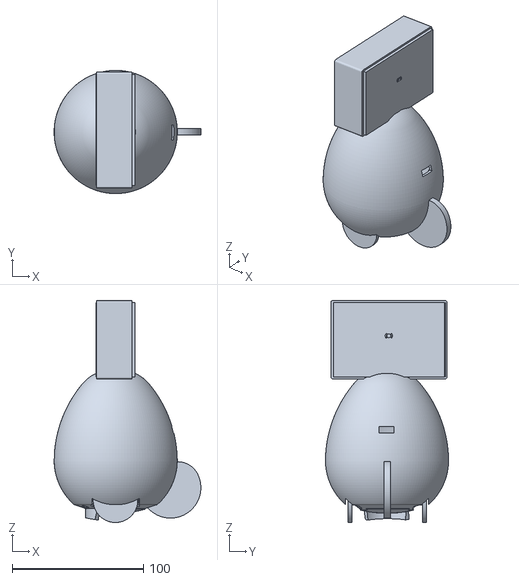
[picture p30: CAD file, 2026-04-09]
fusion360/cubov2 v153.stl
112.0 x 94.0 x 169.4

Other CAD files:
fusion360/cubov2 v152.f3z

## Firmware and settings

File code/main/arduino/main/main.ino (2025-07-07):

#include <TinyStepper_28BYJ_48.h>
#include <ezButton.h>
#include <Wire.h>
// code by surya for QMC5883P from datasheet https://www.qstcorp.com/upload/pdf/202202/%EF%BC%88%E5%B7%B2%E4%BC%A0%EF%BC%8913-52-19%20QMC5883P%20Datasheet%20Rev.C(1).pdf

#define compass_address  0x2C
//
// pin assignments, any digital pins can be used
//
const int LED_PIN = 13;

const int MOTORX_IN1_PIN = 4;
const int MOTORX_IN2_PIN = 5;
const int MOTORX_IN3_PIN = 6;
const int MOTORX_IN4_PIN = 7;

const int MOTORY_IN1_PIN = 8;
const int MOTORY_IN2_PIN = 9;
const int MOTORY_IN3_PIN = 10;
const int MOTORY_IN4_PIN = 11;


const int SW1 = A5;
const int SW2 = A4;
const int SW3 = A3;
const int SW4 = A2;

const int STEPS_PER_REVOLUTION = 2048;

TinyStepper_28BYJ_48 stepperX;
TinyStepper_28BYJ_48 stepperY;

String inputString = "";      // a String to hold incoming data
bool stringComplete = false;  // whether the string is complete


//
// move both X & Y motors together in a coordinated way, such that they each
// start and stop at the same time, even if one motor moves a greater distance
//

ezButton button1(SW1);
ezButton button2(SW2);
ezButton button3(SW3);
ezButton button4(SW4);

int activityCount = 0;
unsigned long lastCheck = 0;
const unsigned long window = 5000;  // 5 seconds
const int activityThreshold = 20;   // Adjust as needed




void compass_WriteReg(byte Reg, byte val) {
  Wire.beginTransmission(compass_address);  //start talking
  Wire.write(Reg);                          // Tell the HMC5883 to Continuously Measure
  Wire.write(val);                          // Set the Register
  Wire.endTransmission();
}

byte compass_ReadReg(byte adrs) {
  Wire.beginTransmission(compass_address);  //start talking
  Wire.write(adrs);                         // Set the Register
  Wire.endTransmission();
  Wire.requestFrom(compass_address, 1);
  return Wire.read();
}

void compass_init() {
  compass_WriteReg(0x29, 0x06);  //Write Register 29H by 0x06 (Define the sign for X Y and Z axis)
  compass_WriteReg(0x0B, 0x08);  //Define Set/Reset mode, with Set/Reset On, Field Range 8Guass
  compass_WriteReg(0x0A, 0xCD);  //normal mode,odr = 200HZ
}


void compass_softReset() {
  compass_WriteReg(0x0B, 0x80);  // soft reset
  compass_WriteReg(0x29, 0x06);  //Write Register 29H by 0x06 (Define the sign for X Y and Z axis)
  compass_WriteReg(0x0B, 0x08);  //Define Set/Reset mode, with Set/Reset On, Field Range 8Guass
  compass_WriteReg(0x0A, 0xCD);  //normal mode,odr = 200HZ
}

/**
 * read values from device
 * @return status value:
 *  - 0:success
 *  - 1:data too long to fit in transmit buffer
 *  - 2:received NACK on transmit of address
 *  - 3:received NACK on transmit of data
 *  - 4:other error
 *  - 8:overflow (magnetic field too strong)
 */
int compass_read_val(int* x, int* y, int* z) {

  delay(10);

  byte chip_id = compass_ReadReg(0x00);
  if (chip_id != 0x80) { return 0; }

  *x = (int)(int16_t)(compass_ReadReg(1) | (compass_ReadReg(2) << 8));
  *y = (int)(int16_t)(compass_ReadReg(3) | (compass_ReadReg(4) << 8));
  *z = (int)(int16_t)(compass_ReadReg(5) | (compass_ReadReg(6)<< 8));
  return 1;
}

float compass_azimuth(int* a, int* b) {
  float azimuth = atan2((int)*a, (int)*b) * 180.0 / PI;
  return azimuth < 0 ? 360 + azimuth : azimuth;
}

int compass_read(int* x, int* y, int* z, int* a) {
  int err = compass_read_val(x, y, z);
  *a = compass_azimuth(y, x);
  return err;
}

int x_cmps=10,y_cmps=11,z_cmps=12;
int az_cmps=5;

void setup() {
  // put your setup code here, to run once:
  Serial.begin(9600);
  Serial1.begin(9600);

   Wire.begin();
  compass_init();

  pinMode(SW1, INPUT);
  pinMode(SW2, INPUT);
  pinMode(SW3, INPUT);
  pinMode(SW4, INPUT);

  inputString.reserve(200);
  stepperX.connectToPins(MOTORX_IN1_PIN, MOTORX_IN2_PIN, MOTORX_IN3_PIN, MOTORX_IN4_PIN);
  stepperY.connectToPins(MOTORY_IN1_PIN, MOTORY_IN2_PIN, MOTORY_IN3_PIN, MOTORY_IN4_PIN);

  stepperX.setSpeedInStepsPerSecond(300);
  stepperX.setAccelerationInStepsPerSecondPerSecond(500);

  stepperY.setSpeedInStepsPerSecond(300);
  stepperY.setAccelerationInStepsPerSecondPerSecond(500);



  stepperX.setCurrentPositionInSteps(0);
  stepperY.setCurrentPositionInSteps(0);
}

void run_command(String input) {
  if (inputString.startsWith("sm;")) {
    int s1Val = -1;
    int s2Val = -1;

    // Find s1:
    int s1Index = inputString.indexOf("s1:");
    if (s1Index != -1) {
      int s1End = inputString.indexOf(";", s1Index);
      s1Val = inputString.substring(s1Index + 3, s1End).toInt();
      stepperX.setupRelativeMoveInSteps(s1Val);
    }

    // Find s2:
    int s2Index = inputString.indexOf("s2:");
    if (s2Index != -1) {
      int s2End = inputString.indexOf(";", s2Index);
      if (s2End == -1) s2End = inputString.length();
      s2Val = inputString.substring(s2Index + 3, s2End).toInt();
      stepperY.setupRelativeMoveInSteps(s2Val);
    }
    Serial1.print("ACK;sm");
  } else if (inputString.startsWith("smt1;")) {
    stepperX.setupStop();
    Serial1.print("ACK;smt1");
  } else if (inputString.startsWith("smt2;")) {
    stepperY.setupStop();
    Serial1.print("ACK;smt2");
  } else if (inputString.startsWith("sws;")) {
    Serial1.print("ACK;sws:");
    Serial1.print(digitalRead(SW1));
    Serial1.print(digitalRead(SW2));
    Serial1.print(digitalRead(SW3));
    Serial1.print(digitalRead(SW4));
  }
  else if (inputString.startsWith("swa;")) {
    Serial1.print("ACK;swa:");
    Serial1.print(activityCount);
  } else if (inputString.startsWith("cmps;")) {
    compass_read(&x_cmps,&y_cmps,&z_cmps,&az_cmps);
    Serial1.print("ACK;cmps:");
    Serial1.print(x_cmps);
    Serial1.print(y_cmps);
    Serial1.print(z_cmps);
    Serial1.print(az_cmps);
  }
}

void loop() {
  button1.loop();  // MUST call the loop() function first
  button2.loop();  // MUST call the loop() function first
  button3.loop();  // MUST call the loop() function first
  button4.loop();

  if (button1.isPressed() || button2.isPressed() || button3.isPressed() || button4.isPressed()){
    activityCount += 1;
  }
    

  // put your main code here, to run repeatedly:
  if (Serial1.available()) {
    while (Serial1.available()) {
      // get the new byte:
      char inChar = (char)Serial1.read();
      Serial.println(inChar);
      // add it to the inputString:
      inputString += inChar;
      // if the incoming character is a newline, set a flag so the main loop can
      // do something about it:
      if (inChar == '\n') {
        stringComplete = true;
      }
    }
  }

  if (stringComplete) {
    Serial.println(inputString);
    run_command(inputString);
    // clear the string:
    inputString = "";
    stringComplete = false;
  }

  if ((!stepperX.motionComplete()) || (!stepperY.motionComplete())) {
    stepperX.processMovement();
    stepperY.processMovement();
  }

  if (millis() - lastCheck >= window) {
    if (activityCount >= activityThreshold) {
      Serial.println("⚡ High switch activity detected! Taking action...");
      // <-- Put your action here
    } else {
      Serial.print("Activity count: ");
      Serial.println(activityCount);
    }

    activityCount = 0;
    lastCheck = millis();
  }
}

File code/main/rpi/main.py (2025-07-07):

import serial
import time

from roboeyes import *
import time
from display_fbgen import Framebuffer


start_timer_val = time.perf_counter()  # high-precision timer 

def ticks_ms():
	return (time.perf_counter() - start_timer_val) * 1000

lcd = Framebuffer()

# Start the display
lcd.fill(1)
time.sleep(1)


fps_screen = 7

# Open the serial port (adjust as needed)
ser = serial.Serial(port='/dev/ttyS0', baudrate=9600, timeout=1)  # Use '/dev/ttyUSB0' on Linux


# RoboEyes callback event
def robo_show( roboeyes ):
	lcd.update()

# Plug RoboEyes on any FrameBuffer descendant
robo = RoboEyes( lcd, 480, 320, frame_rate=fps_screen, on_show = robo_show )

# Define some automated eyes behaviour
robo.set_auto_blinker( ON, 4, 2) # Start auto blinker animation cycle -> bool active, int interval, int variation -> turn on/off, set interval between each blink in full seconds, set range for random interval variation in full seconds
robo.set_idle_mode( ON, 5, 2) # Start idle animation cycle (eyes looking in random directions) -> turn on/off, set interval between each eye repositioning in full seconds, set range for random time interval variation in full seconds

# --[ Define eye shapes, all values in pixels ]--
#robo.eyes_width(160, 140) # byte leftEye, byte rightEye
#robo.eyes_height(160, 140) # byte leftEye, byte rightEye
#robo.eyes_radius(8, 8) # byte leftEye, byte rightEye
#robo.eyes_radius(18, 18) # byte leftEye, byte rightEye (looking round when height=width=36)
#robo.eyes_spacing(50) # int space between eyes-> can also be negative

# --[ Cyclops mode ]--
# robo.cyclops = True  #  if turned on, robot has only on eye

# --[ Initial setup animation ]-- 
# Give a second to the eyes to open in their default state
start = ticks_ms()
while ticks_diff( ticks_ms(), start ) < 1000 :
	robo.update()  

# --[ Open/Close Eyes ]-- 
# Auto blinker must be disable to properly run this
#robo.close() # Close Eyes
#robo.open() # Open Eyes

# --[ Define mood, curiosity and position ]--
robo.mood = DEFAULT  # mood expressions, can be TIRED, ANGRY, HAPPY, FROZEN, AFRAID, CURIOUS, DEFAULT
#robo.position = DEFAULT # cardinal directions, can be N, NE, E, SE, S, SW, W, NW, DEFAULT (default = horizontally and vertically centered)

robo.curious = True  # bool on/off -> when turned on, height of the outer eyes increases when moving to the very left or very right

# --[ Set horizontal or vertical flickering ]--
#robo.horiz_flicker(True, 2) # bool on/off, byte amplitude -> horizontal flicker: alternately displacing the eyes in the defined amplitude in pixels
#robo.vert_flicker(True, 2) # bool on/off, byte amplitude -> vertical flicker: alternately displacing the eyes in the defined amplitude in pixels

# --[ Play prebuilt oneshot animations ]--
#robo.confuse() # confused - eyes shaking left and right
#robo.laugh() # laughing - eyes shaking up and down
#robo.wink( right=True ) # make the right Eye Winking


# Send command
ser.write(b'sm;s1:-1000;s2:-1000\n')  # Send as bytes, add newline if Arduino expects it

send_interval = 3  # seconds
last_send_time =  time.perf_counter()

try:
	while True:
		current_time = time.perf_counter()
		if current_time - last_send_time >= send_interval:
			last_send_time = current_time
			ser.reset_input_buffer()
			ser.write(b'swa;\n')
			time.sleep((1/fps_screen)/1.5)
			# Check for incoming data
			response = ser.readline().decode().strip()
			if response:
				if response.startswith("ACK;swa:"):
					value = int(response.split(":")[1])
					if (value > 9):
						robo.mood = HAPPY
						print("PAt Received,Robot happy")
					else:
						robo.mood = DEFAULT

				
		# update eyes drawings
		robo.update()  
		time.sleep((1/fps_screen)/1.5) #set refresh rate slightly below fps of screen

except KeyboardInterrupt:
	print("Keyboard interrupt caught. Exiting gracefully...")
	ser.close()
except Exception as e:
	print(f"An error occurred: {e}")
	ser.close()

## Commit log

2025-07-07 Added Kernel drivers for display and display code
2026-04-09 Added models
    [cubov2 v152.f3z]
2026-04-09 Extra stl model added
    [cubov2 v153.stl]
